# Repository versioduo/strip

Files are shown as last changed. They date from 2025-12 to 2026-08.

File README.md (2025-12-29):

# V2 strip
🚦 MIDI LED Strip

Drives a WS2812 LED strip. LEDs are controlled by incoming MIDI notes, the
brightness is controlled by the note velocity. Different MIDI channels use
different colors.

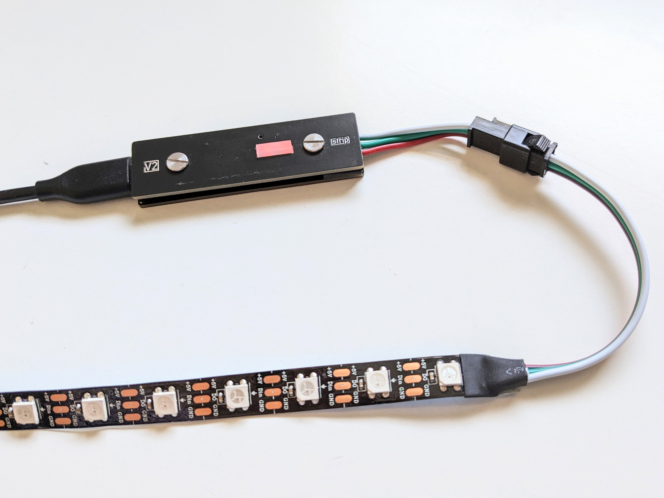
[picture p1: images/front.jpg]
strip hardware


## Screenshot
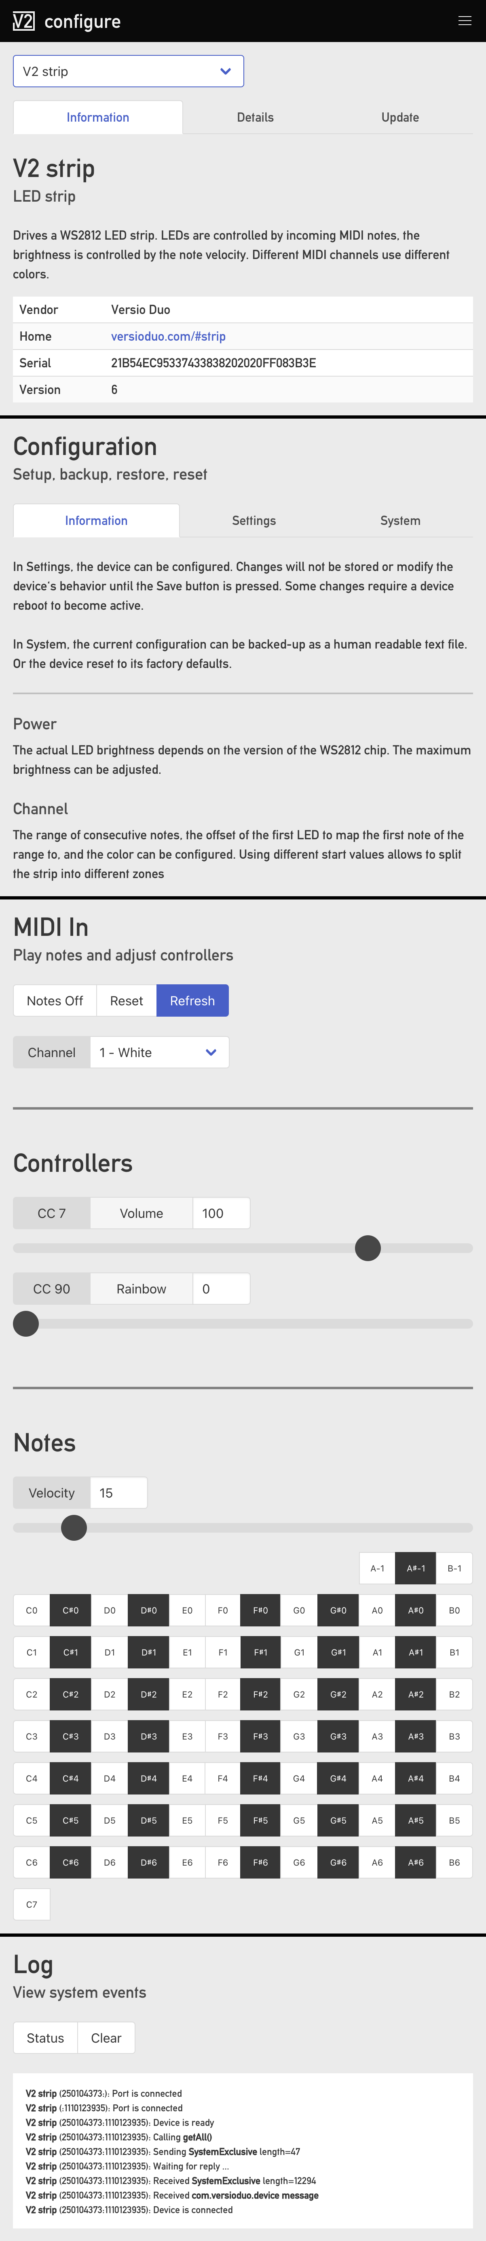
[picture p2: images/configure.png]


# Copying
Anyone can use this public domain work without having to seek authorisation, no one can ever own it.

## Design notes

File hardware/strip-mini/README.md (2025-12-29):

# V2 strip
🚦 MIDI LED Strip

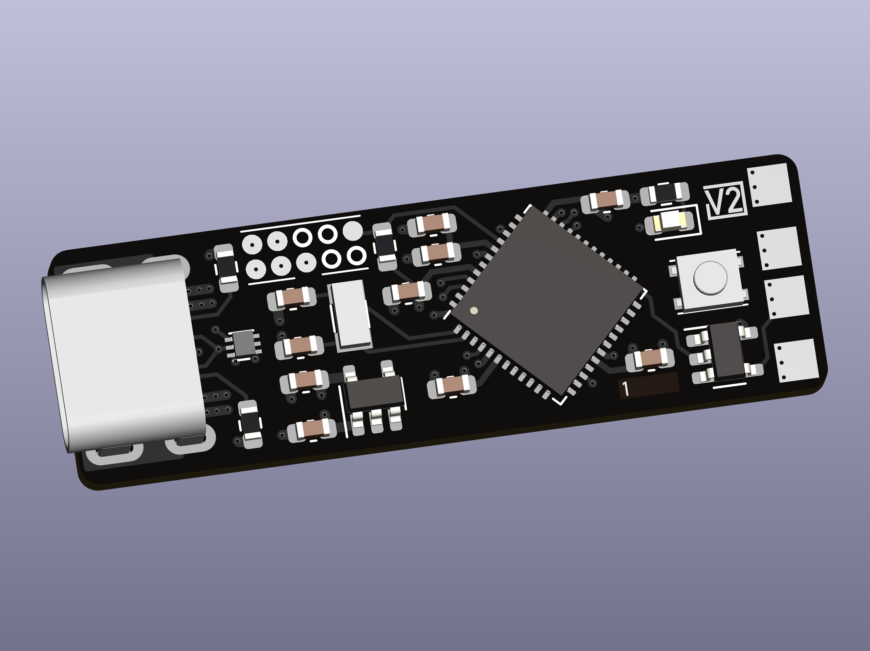
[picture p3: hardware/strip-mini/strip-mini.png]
board


## Video
[YouTube](https://www.youtube.com/watch?v=P1gKQrn-1O4)

## Schematic
[PDF](strip-mini.pdf)

## Bill Of Materials
[Interactive BOM](https://html-preview.github.io/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)

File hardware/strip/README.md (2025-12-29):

# V2 strip
🚦 MIDI LED Strip

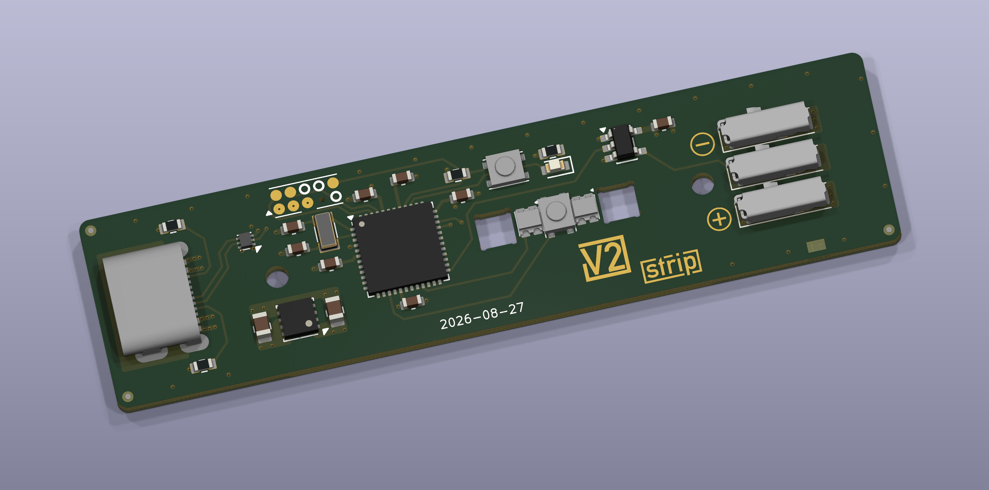
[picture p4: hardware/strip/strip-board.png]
board


## Video
[YouTube](https://www.youtube.com/watch?v=P1gKQrn-1O4)

## Schematic
[PDF](strip.pdf)

## Bill Of Materials
[Interactive BOM](https://html-preview.github.io/?url=https://github.com/versioduo/strip/blob/main/hardware/strip/strip-bom.html)

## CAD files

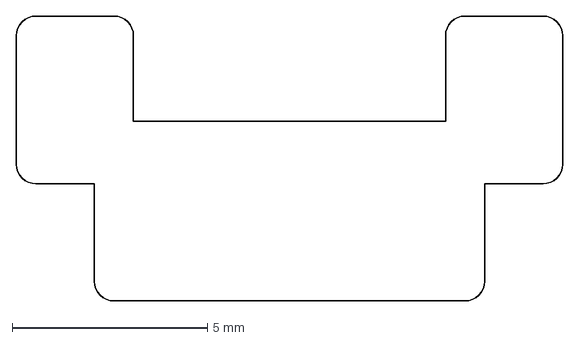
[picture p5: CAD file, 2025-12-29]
hardware/strip/button-laser.dxf
14.0 x 7.30 mm

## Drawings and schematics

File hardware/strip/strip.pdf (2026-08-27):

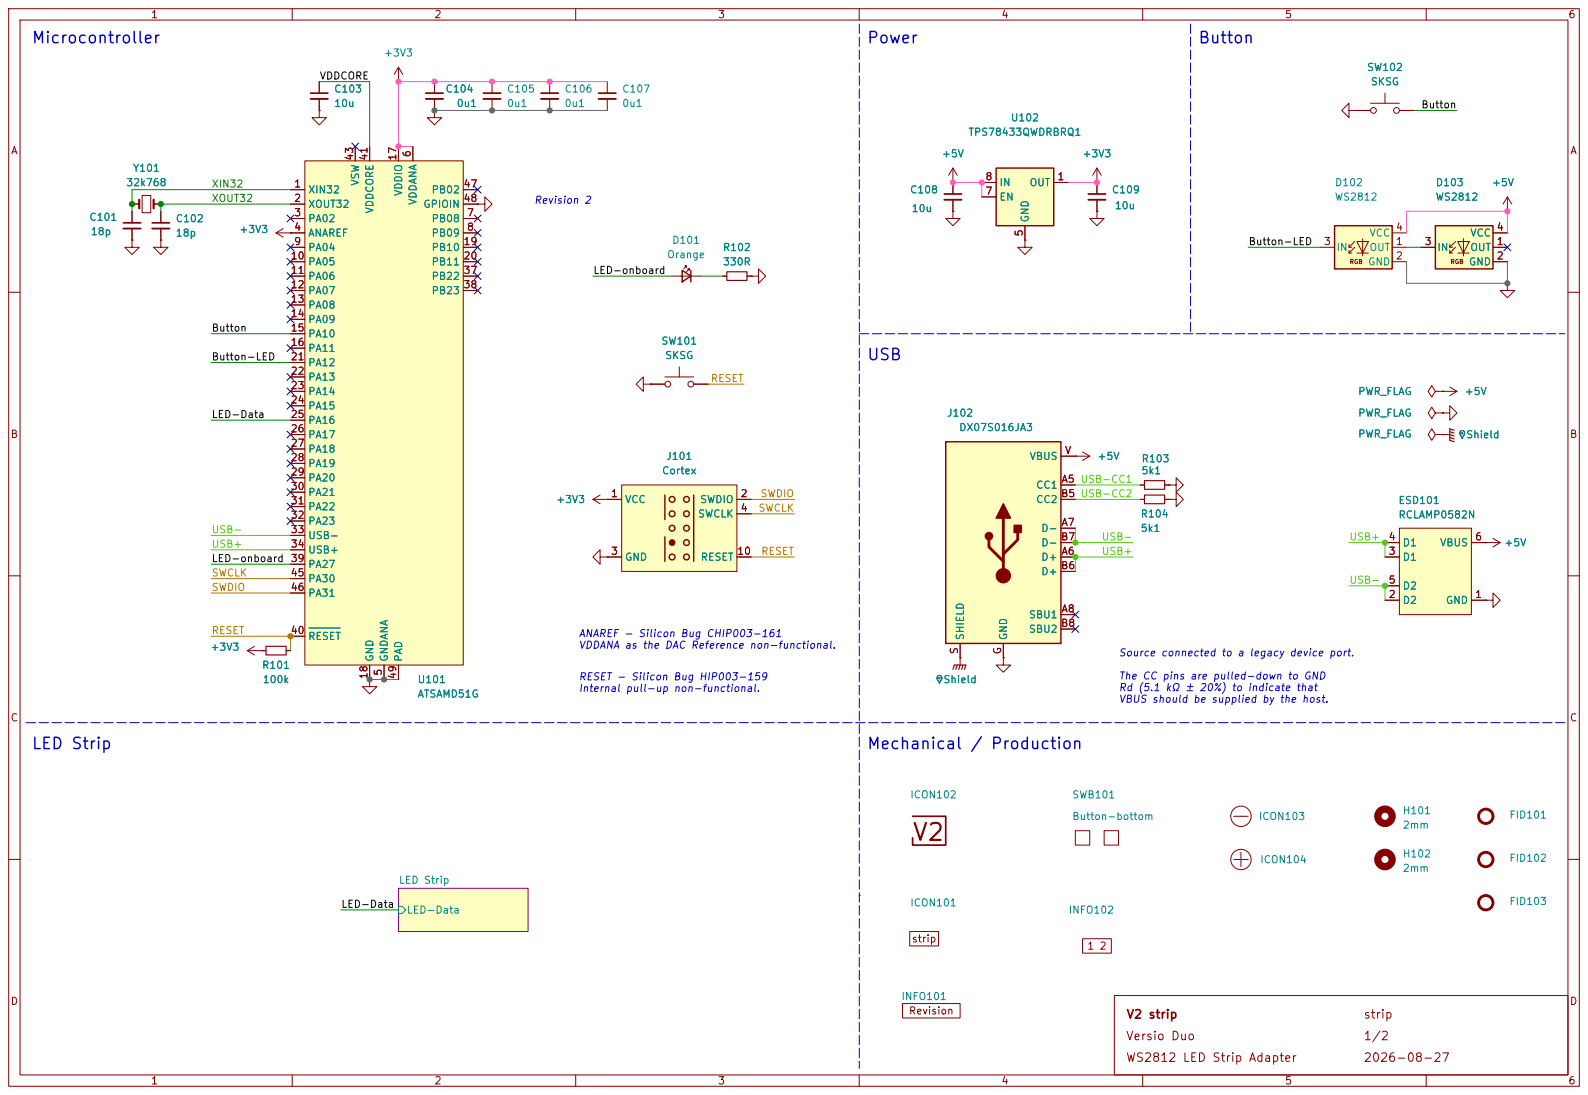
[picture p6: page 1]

Rd (5.1 kΩ ± 20%) to indicate that VBUS should be supplied by the host. Revision 2 RESET - Silicon Bug HIP003-159

LED-Data Button-LED

Source connected to a legacy device port. The CC pins are pulled-down to GND

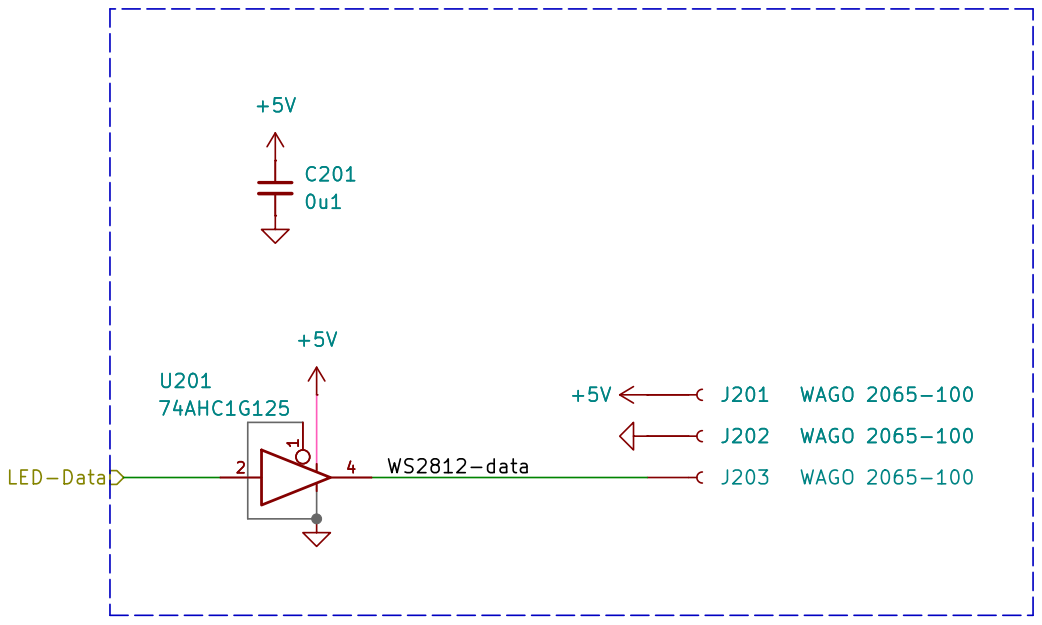
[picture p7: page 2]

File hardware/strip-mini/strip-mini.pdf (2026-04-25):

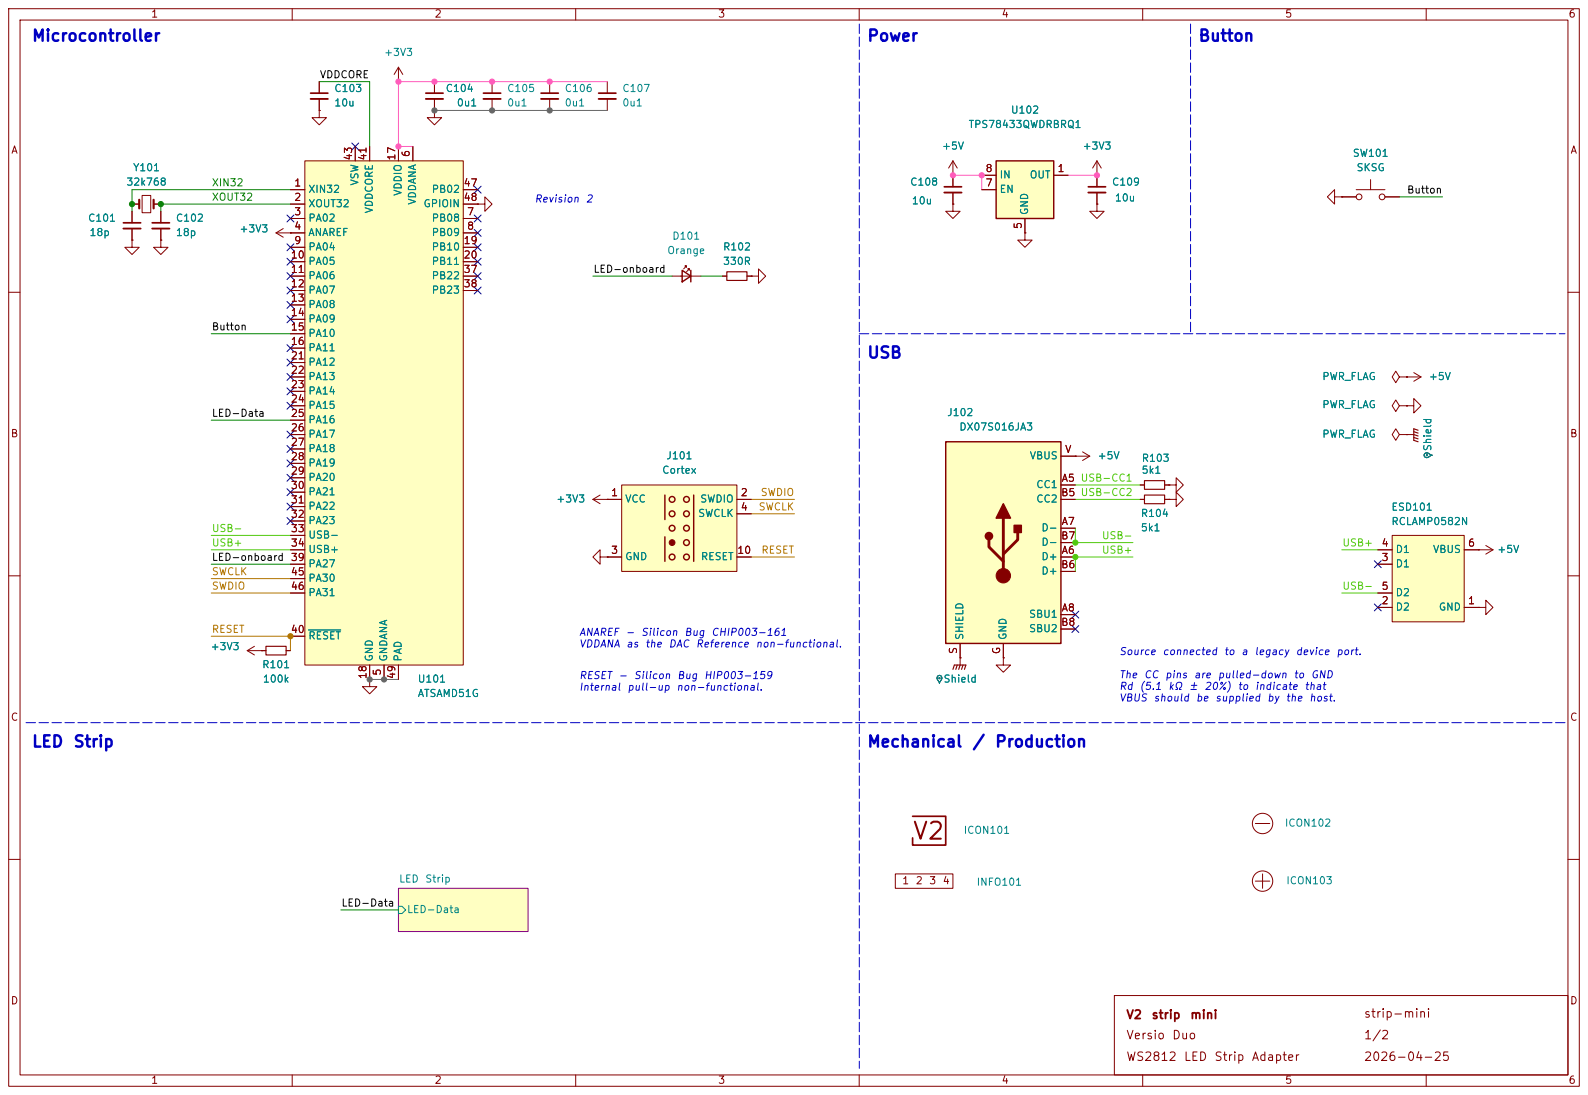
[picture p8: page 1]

Rd (5.1 kΩ ± 20%) to indicate that VBUS should be supplied by the host. Button

Internal pull-up non-functional. Revision 2 LED Strip

Source connected to a legacy device port. The CC pins are pulled-down to GND

strip-mini LED-Data

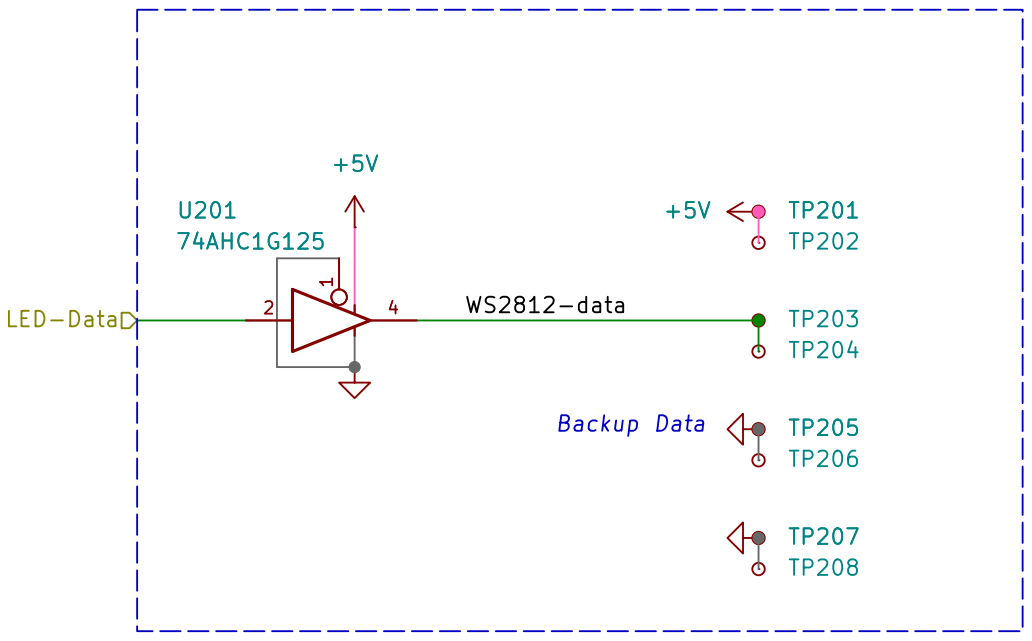
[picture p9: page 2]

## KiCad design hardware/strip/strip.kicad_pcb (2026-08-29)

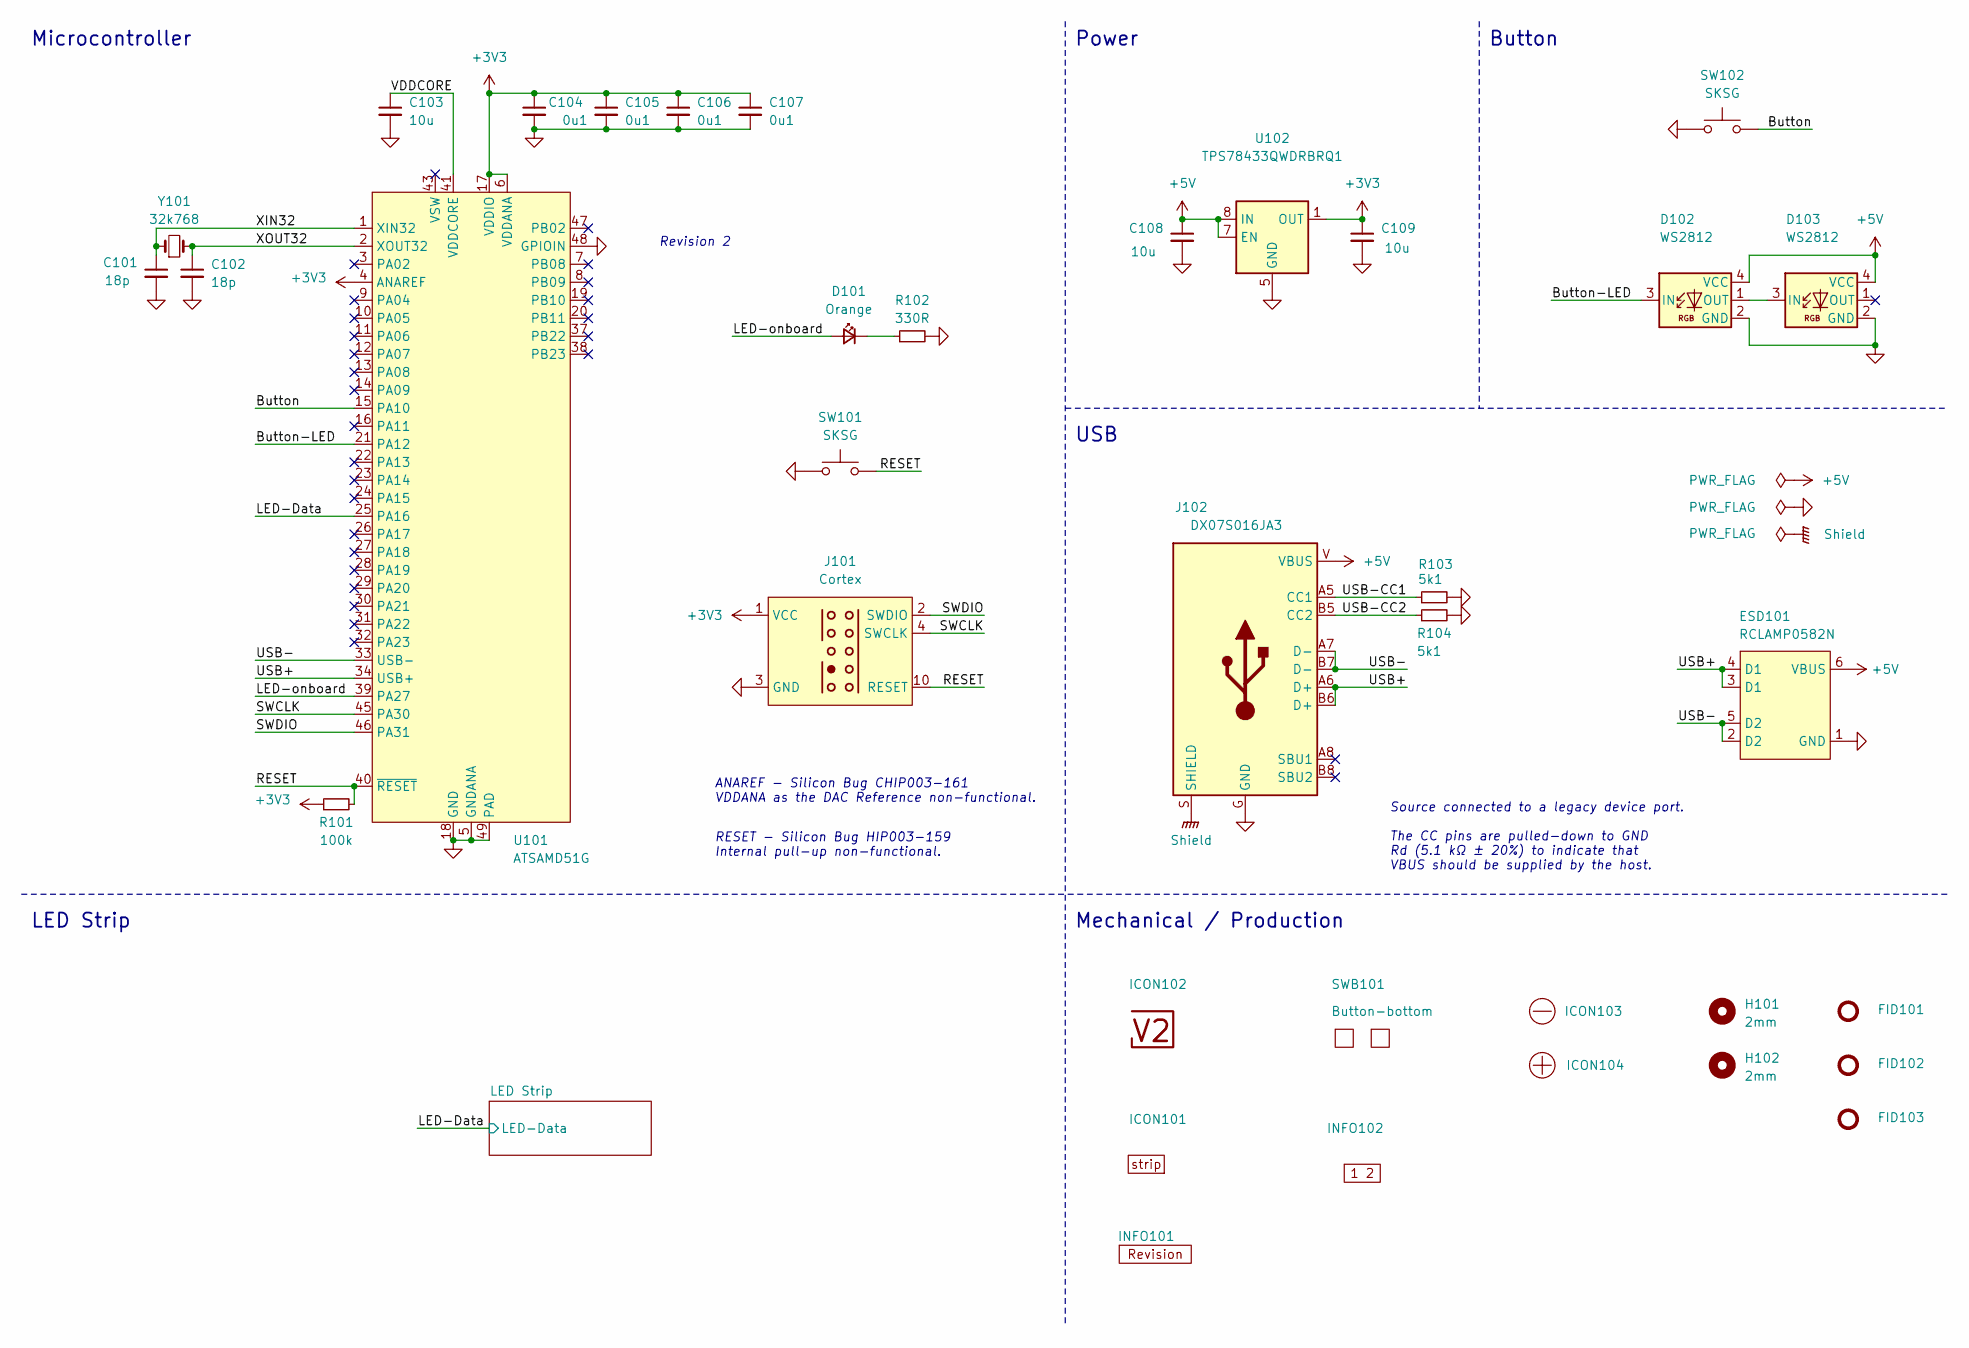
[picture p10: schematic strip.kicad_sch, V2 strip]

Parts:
C101, C102: 18p; C_1608; Rating 50V; Mouser 810-CGA3E2C0G1H180J
C103: 10u; C_1608; Rating 10V; Mouser 810-C1608X6S1A106M
C104, C105, C106, C107: 0u1; C_1608; Rating 50V; Mouser 810-CGA3E2X7R1H104MA
C108, C109: 10u; C_2012; Rating 25V; Mouser 810-C2012X5R1E106K
D101: Orange; LED_1608; Rating 605nm; Mouser 755-SML-D12D1WT86
D102, D103: WS2812; WS2812-2020; Rating 15mA; LCSC C965555
ESD101: RCLAMP0582N; SLP1210N6; Rating 20kV; Mouser 947-RCLAMP0582N.TCT
FID101, FID102, FID103: Fiducial_Paste; Fiducial_0.5mm_Mask1mm_Paste
H101, H102: 2mm; MountingHole_2mm
ICON101: Board_strip; Board_strip_Small
ICON102: V2-logo; Logo_Small
ICON103: Minus; Minus_Small
ICON104: Plus; Plus_Small
INFO101: Revision
INFO102: Layer_Numbers-4
J101: Cortex
J102: DX07S016JA3; JAE_DX07S016JA3; Rating USB2.0; Mouser 656-DX07S016JA3R1500
R101: 100k; R_1608; Rating 100mW; Mouser 71-CRCW0603100KFKEAC
R102: 330R; R_1608; Rating 100mW; Mouser 71-CRCW0603330RFKEAC
R103, R104: 5k1; R_1608; Rating 100mW; Mouser 71-CRCW06035K10FKEAC
SW101, SW102: SKSG; Rating 1.6N; Mouser 688-SKSGACE010
SWB101: Button-bottom; PCB_Button-bottom
U101: ATSAMD51G; QFN-48-1EP_7x7mm_P0.5mm_EP5.45x5.45mm_ThermalVias; Rating Cortex-M4F; Mouser 556-ATSAMD51G19AMU
U102: TPS78433QWDRBRQ1; VSON-8-1_3x3mm_P0.65_EP1.65x2.4mm; Rating 300mA; Mouser 595-TPS78433QWDRBRQ1
Y101: 32k768; Crystal_SMD_3215-2Pin_3.2x1.5mm; Rating 10ppm; Mouser 815-ABS0716632.768KT

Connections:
+3V3: C104.1, C105.1, C106.1, C107.1, C109.1, J101.1 (VCC), R101.1, U101.4 (ANAREF), U101.6 (VDDANA), U101.17 (VDDIO), U101.36 (VDDIO), U101.44 (VDDIO), U102.1 (OUT)
+5V: C108.1, D102.4 (VCC), D103.4 (VCC), ESD101.6 (VBUS), J102.V (VBUS), U102.6 (EN), U102.7 (EN), U102.8 (IN); also elsewhere on the board
/Button: SW102.2, U101.15 (PA10)
/Button-LED: D102.3 (IN), U101.21 (PA12)
/LED-Data: U101.25 (PA16); also elsewhere on the board
/LED-onboard: D101.2 (A), U101.39 (PA27)
/RESET: J101.10 (RESET), R101.2, SW101.2, U101.40 (~RESET)
/SWCLK: J101.4 (SWCLK), U101.45 (PA30)
/SWDIO: J101.2 (SWDIO), U101.46 (PA31)
/Shield: J102.S (SHIELD)
/USB+: ESD101.3 (D1), ESD101.4 (D1), J102.A6 (D+), J102.B6 (D+), U101.34 (USB+)
/USB-: ESD101.2 (D2), ESD101.5 (D2), J102.A7 (D-), J102.B7 (D-), U101.33 (USB-)
/USB-CC1: J102.A5 (CC1), R103.1
/USB-CC2: J102.B5 (CC2), R104.1
/VDDCORE: C103.1, U101.41 (VDDCORE)
/XIN32: C101.1, U101.1 (XIN32), Y101.1
/XOUT32: C102.1, U101.2 (XOUT32), Y101.2
GND: C101.2, C102.2, C103.2, C104.2, C105.2, C106.2, C107.2, C108.2, C109.2, D102.2 (GND), D103.2 (GND), ESD101.1 (GND), J101.3 (GND), J101.5 (GND), J102.G (GND), R102.2, R103.2, R104.2, SW101.1, SW102.1, U101.5 (GNDANA), U101.18 (GND), U101.35 (GND), U101.42 (GND), U101.48 (GPIOIN), U101.49 (PAD), U102.5 (GND), U102.9 (GND); also elsewhere on the board
unnamed: D101.1 (K), R102.1
unnamed: D102.1 (OUT), D103.3 (IN)

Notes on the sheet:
ANAREF -  Silicon Bug CHIP003-161 VDDANA as the DAC Reference non-functional.
RESET -  Silicon Bug HIP003-159 Internal pull-up non-functional.
 Source connected to a legacy device port. The CC pins are pulled-down to GND Rd (5.1 kΩ ± 20%) to indicate that VBUS should be supplied by the host.
Button
Revision 2
Power
Mechanical / Production
Microcontroller
USB
LED Strip

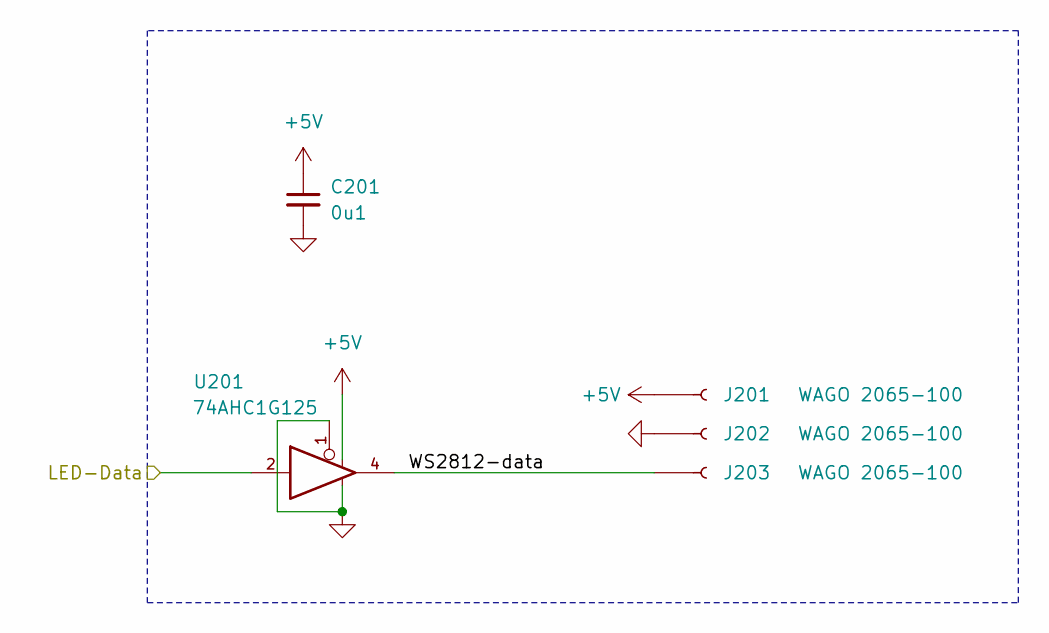
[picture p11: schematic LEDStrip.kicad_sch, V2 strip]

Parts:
C201: 0u1; C_1608; Rating 50V; Mouser 810-CGA3E2X7R1H104MA
J201, J202, J203: WAGO 2065-100; 2065-100; Rating 9A
U201: 74AHC1G125; SOT-23-5; Rating 8mA; Mouser 595-SN74AHC1G125DBVR

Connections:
+5V: C201.1, J201.1, U201.5; also elsewhere on the board
/LED Strip/WS2812-data: J203.1, U201.4
/LED-Data: U201.2; also elsewhere on the board
GND: C201.2, J202.1, U201.1, U201.3; also elsewhere on the board

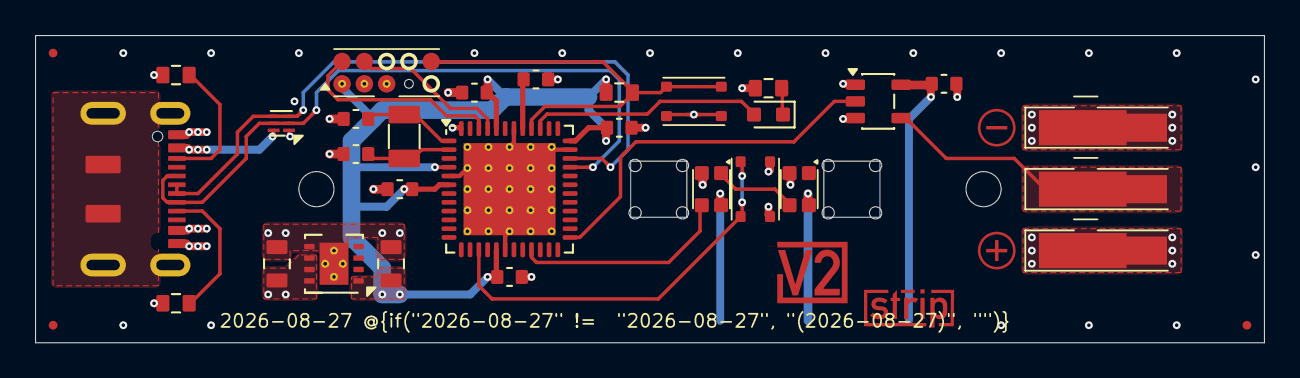
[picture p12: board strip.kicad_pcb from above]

Board: 4 copper layers, 70.0 x 17.5 mm, 41 parts (0 on the bottom side), 20 nets.

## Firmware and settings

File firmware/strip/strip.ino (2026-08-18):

#include <V2Base.h>
#include <V2Buttons.h>
#include <V2Device.h>
#include <V2LED.h>
#include <V2MIDI.h>
#include <V2Music.h>

namespace {
  V2Device::Info     Info{V2DeviceInfo("com.versioduo.strip", 19, "versioduo:samd:strip")};
  V2LED::WS2812<2>   LED(PIN_LED_WS2812, sercom2, SPI_PAD_0_SCK_1, PIO_SERCOM);
  V2LED::WS2812<128> LEDExt(PIN_LED_WS2812_EXT, sercom1, SPI_PAD_0_SCK_1, PIO_SERCOM);

  // Config, written to EEPROM.
  constexpr struct Configuration {
    enum class Program : uint8_t { Notes, Bar, _count };
    struct {
      uint8_t count{88};
      bool    reverse{};
      float   power{0.5};
    } leds;

    struct {
      char    name[32];
      uint8_t note{V2MIDI::A(-1)};
      uint8_t count{88};
      uint8_t start{};
      Program program{};
      struct {
        uint8_t h{0};
        uint8_t s{0};
        uint8_t v{127};
      } colour;
    } channels[16];

    float cNotes{};
  } ConfigurationDefault{.channels{
    {.name{"White"}},
    {.name{"Red"}, .colour{.h{0}, .s{127}}},
    {.name{"Green"}, .colour{.h{42}, .s{127}}},
    {.name{"Blue"}, .colour{.h{85}, .s{127}}},
    {.name{"Cyan"}, .colour{.h{63}, .s{127}}},
    {.name{"Magenta"}, .colour{.h{106}, .s{127}}},
    {.name{"Yellow"}, .colour{.h{21}, .s{127}}},
    {.name{"Orange"}, .colour{.h{11}, .s{127}}},
    {.name{"Amber"}, .colour{.h{8}, .s{127}}},
    {.name{"Pink"}, .colour{.h{116}, .s{100}}},
    {.name{"Lavender"}, .colour{.h{95}, .s{70}}},
    {.name{"Champagne"}, .colour{.h{12}, .s{100}}},
    {.name{"Desert"}, .colour{.h{10}, .s{40}}},
    {.name{"Aquamarine"}, .colour{.h{56}, .s{127}}},
    {.name{"Cornflower"}, .colour{.h{78}, .s{100}}},
    {.name{"Aqua"}, .colour{.h{77}, .s{50}}},
  }};

  class Device : public V2Device {
  public:
    Device() : V2Device() {
      metadata.vendor      = "Versio Duo";
      metadata.product     = "V2 strip";
      metadata.description = "LED strip";
      metadata.home        = "https://versioduo.com/#strip";
      help.device          = "Drives a WS2812 LED strip. LEDs are controlled by incoming MIDI notes, the "
                             "brightness is controlled by the note velocity. Different MIDI channels use "
                             "different colours.";
      help.configuration   = "# Power\n"
                             "The actual LED brightness depends on the version of the WS2812 "
                             "chip. The maximum brightness can be adjusted.\n"
                             "# Channel\n"
                             "The range of consecutive notes, the offset of the first LED to map the "
                             "first note of the range to, and the colour can be configured. Using "
                             "different start values allows to split the strip into different zones";
      system.download      = "https://versioduo.com/download";
      system.configure     = "https://versioduo.com/configure";
      usb.ports.standard   = 0;
      configuration        = {.version{2}, .size{sizeof(config)}, .data{&config}};
    }

    enum class CC {
      Volume  = V2MIDI::CC::ChannelVolume,
      CNotes  = V2MIDI::CC::Controller85,
      Rainbow = V2MIDI::CC::Controller90,
    };

    Configuration config{ConfigurationDefault};

    void updateRainbow(float brightness) {
      LEDExt.rainbow(1, 4.5f - (_rainbow * 4.f), brightness);
    }

  private:
    const char* _programNames[(uint8_t)Configuration::Program::_count]{"Notes", "Bar"};

    struct {
      uint8_t aftertouch;

      struct {
        bool                  active;
        V2Music::Playing<128> playing;
      } bar;

      struct {
        uint8_t velocity;
        uint8_t aftertouch;
      } notes[128];
    } _channels[16]{};

    struct {
      uint8_t channel;
      uint8_t brightness;
    } _leds[128]{};

    float               _volume{100.f / 127.f};
    float               _cNotes{};
    float               _rainbow{};
    uint32_t            _timeoutUsec{};
    V2Music::ForcedStop _force;

    void handleReset() override {
      _timeoutUsec = 0;
      _force.reset();

      allNotesOff();
    }

    void handleLoop() override {
      if (_timeoutUsec > 0 && V2Base::getUsecSince(_timeoutUsec) > 900 * 1000 * 1000)
        reset();
    }

    void allNotesOff() {
      if (_force.trigger()) {
        reset();
        return;
      }

      for (uint8_t ch = 0; ch < 16; ch++) {
        _channels[ch].aftertouch = 0;
        _channels[ch].bar.playing.reset();

        for (uint8_t i = 0; i < V2Base::countof(_channels[0].notes); i++) {
          _channels[ch].notes[i].aftertouch = 0;
          _channels[ch].notes[i].velocity   = 0;
        }
      }

      for (uint8_t i = 0; i < V2Base::countof(_leds); i++)
        _leds[i] = {};

      _volume  = 100.f / 127.f;
      _cNotes  = config.cNotes;
      _rainbow = 0;
      LED.reset();
      LED.hsv({V2Colour::Orange, 0.95, 0.25});

      LEDExt.reset();
      updateLEDs(true);
    }

    // Show individual notes.
    void updateLEDsNotes(bool force = false) {
      for (uint8_t i = 0; i < config.leds.count; i++) {
        uint8_t channel    = 0;
        uint8_t brightness = 0;

        // Find an active note in one of the 16 channels. The note in the
        // highest channel number wins.
        for (int8_t ch = 15; ch >= 0; ch--) {
          if (config.channels[ch].program != Configuration::Program::Notes)
            continue;

          if (i < config.channels[ch].start)
            continue;

          if (i >= config.channels[ch].start + config.channels[ch].count)
            continue;

          const uint8_t note = config.channels[ch].note + i - config.channels[ch].start;
          if (note > 127)
            continue;

          if (_channels[ch].notes[note].velocity == 0)
            continue;

          channel = ch;
          if (_channels[ch].notes[note].aftertouch > 0) {
            brightness = _channels[ch].notes[note].aftertouch;
          }

          else if (_channels[channel].aftertouch > 0) {
            brightness = _channels[channel].aftertouch;
          }

          else {
            brightness = _channels[ch].notes[note].velocity;
          }

          break;
        }

        if (brightness == 0 && _cNotes > 0.f) {
          uint8_t note = V2MIDI::A(-1) + i;
          uint8_t key  = note % 12;
          if (key == 0)
            brightness = _cNotes * 127.f;
        }

        if (!force && _leds[i].channel == channel && _leds[i].brightness == brightness)
          continue;

        _leds[i].channel    = channel;
        _leds[i].brightness = brightness;

        if (brightness == 0) {
          LEDExt.brightness(0, i);
          continue;
        }

        auto h{(float)config.channels[channel].colour.h / 127.f * 360.f};
        auto s{(float)config.channels[channel].colour.s / 127.f};
        auto v{(float)config.channels[channel].colour.v / 127.f};
        auto fraction{(float)brightness / 127.f};
        auto adjusted{0.1f + (0.9f * fraction)};
        LEDExt.hsv({h, s, _volume * adjusted * v}, i);
      }
    }

    // Flash an LED bar, the length depending on the note velocity.
    void updateLEDsBar() {
      for (int8_t ch = 15; ch >= 0; ch--) {
        if (config.channels[ch].program != Configuration::Program::Bar)
          continue;

        uint8_t note;
        uint8_t velocity;
        if (!_channels[ch].bar.playing.getLast(note, velocity)) {
          if (!_channels[ch].bar.active)
            continue;

          for (uint8_t i = 0; i < config.channels[ch].count; i++)
            LEDExt.brightness(0, config.channels[ch].start + i);

          _channels[ch].bar.active = false;
          continue;
        }

        auto h{float{config.channels[ch].colour.h / 127.f * 360.f}};
        auto s{float{config.channels[ch].colour.s / 127.f}};
        auto v{float{config.channels[ch].colour.v / 127.f}};
        auto fractionBrightness{float(_channels[ch].aftertouch > 0 ? _channels[ch].aftertouch : 127.f) / 127.f};
        auto brightness{_volume * fractionBrightness * v};
        auto count{ceilf((float)config.channels[ch].count * ((float)velocity / 127.f))};
        for (uint8_t i = 0; i < count; i++)
          LEDExt.hsv({h, s, brightness}, config.channels[ch].start + i);

        for (uint8_t i = count; i < config.channels[ch].count; i++)
          LEDExt.brightness(0, config.channels[ch].start + i);

        _channels[ch].bar.active = true;
      }
    }

    void updateLEDs(bool force = false) {
      updateLEDsNotes(force);
      updateLEDsBar();
    }

    void handleNote(uint8_t channel, uint8_t note, uint8_t velocity) override {
      switch (config.channels[channel].program) {
        case Configuration::Program::Notes:
          _channels[channel].notes[note].velocity = velocity;
          if (velocity == 0) {
            _channels[channel].aftertouch             = 0;
            _channels[channel].notes[note].aftertouch = 0;
          }
          break;

        case Configuration::Program::Bar:
          _channels[channel].bar.playing.update(note, velocity);
          break;
      }

      updateLEDs();
      _timeoutUsec = V2Base::getUsec();
    }

    void handleNoteOff(uint8_t channel, uint8_t note, uint8_t velocity) override {
      handleNote(channel, note, 0);
      _timeoutUsec = V2Base::getUsec();
    }

    void handleAftertouch(uint8_t channel, uint8_t note, uint8_t pressure) override {
      _channels[channel].notes[note].aftertouch = pressure;

      updateLEDs();
      _timeoutUsec = V2Base::getUsec();
    }

    void handleAftertouchChannel(uint8_t channel, uint8_t pressure) override {
      _channels[channel].aftertouch = pressure;

      updateLEDs();
      _timeoutUsec = V2Base::getUsec();
    }

    void handleControlChange(uint8_t channel, uint8_t controller, uint8_t value) override {
      switch (controller) {
        case (uint8_t)CC::Volume:
          _volume = (float)value / 127.f;
          if (_rainbow > 0.f)
            updateRainbow(_volume);

          else
            updateLEDs(true);
          break;

        case (uint8_t)CC::CNotes:
          _cNotes = (float)value / 127.f;
          updateLEDs(true);
          break;

        case (uint8_t)CC::Rainbow:
          _rainbow = (float)value / 127.f;
          if (_rainbow <= 0.f) {
            LEDExt.reset();
            updateLEDs(true);

          } else {
            updateRainbow(_volume);
          }
          break;

        case V2MIDI::CC::AllSoundOff:
        case V2MIDI::CC::AllNotesOff:
          allNotesOff();
          break;
      }

      _timeoutUsec = V2Base::getUsec();
    }

    void handleSystemExclusive(const uint8_t* buffer, uint32_t len) override {
      if (len < 10)
        return;

      // 0x7d == SysEx prototype/research/private ID
      if (buffer[1] != 0x7d)
        return;

      // Handle only JSON messages.
      if (buffer[2] != '{' || buffer[len - 2] != '}')
        return;

      // Read incoming message.
      JsonDocument json;
      if (deserializeJson(json, buffer + 2, len - 1))
        return;

      JsonObject jsonLed = json["led"];
      if (!jsonLed)
        return;

      JsonArray jsonColours = jsonLed["colours"];
      if (!jsonColours)
        return;

      const uint8_t start = jsonLed["start"];
      for (uint8_t i = 0; i + start < 128; i++) {
        JsonArray jsonColour = jsonColours[i];
        if (!jsonColour)
          break;

        // Empty array, skip LED.
        if (jsonColour[2].isNull())
          continue;

        uint8_t hue = jsonColour[0];
        if (hue > 127)
          hue = 127;

        uint8_t saturation = jsonColour[1];
        if (saturation > 127)
          saturation = 127;

        uint8_t brightness = jsonColour[2];
        if (brightness > 127)
          brightness = 127;

        LEDExt.hsv({float(hue) / 127.f * 360.f, float(saturation) / 127.f, float(brightness) / 127.f}, i + start);
      }

      _timeoutUsec = V2Base::getUsec();
    }

    void handleSystemReset() override {
      reset();
    }

    void exportInput(JsonObject json) override {
      JsonArray jsonChannels = json["channels"].to<JsonArray>();
      for (uint8_t ch = 0; ch < 16; ch++) {
        JsonObject jsonChannel = jsonChannels.add<JsonObject>();
        jsonChannel["number"]  = ch;
        jsonChannel["name"]    = config.channels[ch].name;

        JsonArray jsonControllers = jsonChannel["controllers"].to<JsonArray>();
        {
          JsonObject jsonController = jsonControllers.add<JsonObject>();
          jsonController["name"]    = "Volume";
          jsonController["number"]  = (uint8_t)CC::Volume;
          jsonController["value"]   = (uint8_t)(_volume * 127.f);
        }
        {
          JsonObject jsonController = jsonControllers.add<JsonObject>();
          jsonController["name"]    = "C Notes";
          jsonController["number"]  = (uint8_t)CC::CNotes;
          jsonController["value"]   = (uint8_t)(_cNotes * 127.f);
        }
        {
          JsonObject jsonController = jsonControllers.add<JsonObject>();
          jsonController["name"]    = "Rainbow";
          jsonController["number"]  = (uint8_t)CC::Rainbow;
          jsonController["value"]   = (uint8_t)(_rainbow * 127.f);
        }
        {
          JsonObject jsonAftertouch = jsonChannel["aftertouch"].to<JsonObject>();
          jsonAftertouch["value"]   = _channels[ch].aftertouch;
        }
        {
          JsonObject jsonChromatic = jsonChannel["chromatic"].to<JsonObject>();
          switch (config.channels[ch].program) {
            case Configuration::Program::Notes:
              jsonChromatic["start"] = config.channels[ch].note;
              jsonChromatic["count"] = config.channels[ch].count;
              break;

            case Configuration::Program::Bar:
              jsonChromatic["start"] = 0;
              jsonChromatic["count"] = 127;
              break;
          }
        }
      }
    }

    void exportSettings(JsonArray json) override {
      {
        JsonObject setting = json.add<JsonObject>();
        setting["type"]    = "number";
        setting["title"]   = "LED";
        setting["label"]   = "Count";
        setting["min"]     = 1;
        setting["max"]     = 128;
        setting["default"] = ConfigurationDefault.leds.count;
        setting["path"]    = "leds/count";
      }
      {
        JsonObject setting = json.add<JsonObject>();
        setting["type"]    = "toggle";
        setting["label"]   = "Reverse";
        setting["default"] = ConfigurationDefault.leds.reverse;
        setting["path"]    = "leds/reverse";
      }
      {
        JsonObject setting = json.add<JsonObject>();
        setting["type"]    = "number";
        setting["label"]   = "Power";
        setting["min"]     = 0;
        setting["max"]     = 1;
        setting["step"]    = 0.01;
        setting["default"] = ConfigurationDefault.leds.power;
        setting["path"]    = "leds/power";
      }
      {
        JsonObject setting = json.add<JsonObject>();
        setting["type"]    = "number";
        setting["title"]   = "Guide";
        setting["label"]   = "C Notes";
        setting["min"]     = 0;
        setting["max"]     = 1;
        setting["step"]    = 0.01;
        setting["default"] = ConfigurationDefault.cNotes;
        setting["path"]    = "cNotes";
      }

      for (uint8_t ch = 0; ch < 16; ch++) {
        {
          JsonObject setting = json.add<JsonObject>();
          setting["type"]    = "title";

          char name[64];
          sprintf(name, "Channel %d", ch + 1);
          setting["title"] = name;
        }
        {
          JsonObject setting = json.add<JsonObject>();
          setting["type"]    = "text";
          setting["label"]   = "Name";

          char path[64];
          sprintf(path, "channels[%d]/name", ch);
          setting["path"] = path;
        }
        {
          JsonObject setting = json.add<JsonObject>();
          setting["type"]    = "number";
          setting["label"]   = "Program";
          setting["max"]     = (uint8_t)Configuration::Program::_count - 1;
          setting["input"]   = "select";
          JsonArray names    = setting["names"].to<JsonArray>();
          for (uint8_t i = 0; i < (uint8_t)Configuration::Program::_count; i++)
            names.add(_programNames[i]);

          char path[64];
          sprintf(path, "channels[%d]/program", ch);
          setting["path"] = path;
        }
        {
          JsonObject setting = json.add<JsonObject>();
          setting["type"]    = "number";
          setting["label"]   = "LED";
          setting["text"]    = "Start";
          setting["min"]     = 1;
          setting["max"]     = 128;

          char path[64];
          sprintf(path, "channels[%d]/start", ch);
          setting["path"] = path;
        }
        {
          JsonObject setting = json.add<JsonObject>();
          setting["type"]    = "number";
          setting["label"]   = "LED";
          setting["text"]    = "Count";
          setting["max"]     = 128;

          char path[64];
          sprintf(path, "channels[%d]/count", ch);
          setting["path"] = path;
        }
        {
          JsonObject setting = json.add<JsonObject>();
          setting["type"]    = "note";
          setting["label"]   = "Note";

          setting["default"] = ConfigurationDefault.channels[ch].note;

          char path[64];
          sprintf(path, "channels[%d]/note", ch);
          setting["path"] = path;
        }
        {
          JsonObject setting = json.add<JsonObject>();
          setting["type"]    = "colour";
          setting["ruler"]   = true;

          char path[64];
          sprintf(path, "channels[%d]/colour", ch);
          setting["path"] = path;
        }
      }
    }

    void importConfiguration(JsonObject json) override {
      JsonObject jsonLeds = json["leds"];
      if (jsonLeds) {
        if (!jsonLeds["count"].isNull()) {
          uint8_t count = jsonLeds["count"];
          if (count > 128)
            count = 128;
          config.leds.count = count;
        }

        if (!jsonLeds["reverse"].isNull())
          config.leds.reverse = jsonLeds["reverse"];

        if (!jsonLeds["power"].isNull())
          config.leds.power = jsonLeds["power"];
      }

      if (!json["cNotes"].isNull()) {
        float cNotes = json["cNotes"];
        if (cNotes > 1.f) {
          cNotes = 1;
        }

        else if (cNotes < 0.f) {
          cNotes = 0;
        }

        config.cNotes = cNotes;
      }

      JsonArray jsonChannels = json["channels"];
      if (jsonChannels) {
        for (uint8_t ch = 0; ch < 16; ch++) {
          if (jsonChannels[ch].isNull())
            break;

          const char* name = jsonChannels[ch]["name"];
          if (name)
            strlcpy(config.channels[ch].name, name, sizeof(config.channels[ch].name));

          if (!jsonChannels[ch]["program"].isNull()) {
            uint16_t program = jsonChannels[ch]["program"];
            if (program > (uint8_t)Configuration::Program::_count - 1)
              program = (uint8_t)Configuration::Program::_count - 1;

            config.channels[ch].program = (Configuration::Program)program;
          }

          if (!jsonChannels[ch]["start"].isNull()) {
            uint16_t led = jsonChannels[ch]["start"];
            if (led < 1)
              led = 1;
            if (led > 128)
              led = 128;

            config.channels[ch].start = led - 1;
          }

          if (!jsonChannels[ch]["count"].isNull()) {
            uint16_t count = jsonChannels[ch]["count"];
            if (count > 128)
              count = 128;

            config.channels[ch].count = count;
          }

          if (!jsonChannels[ch]["note"].isNull()) {
            uint16_t note = jsonChannels[ch]["note"];
            if (note > 127)
              note = 127;

            config.channels[ch].note = note;
          }

          JsonArray jsonColour = jsonChannels[ch]["colour"];
          if (!jsonColour)
            jsonColour = jsonChannels[ch]["color"];
          if (jsonColour) {
            uint8_t colour = jsonColour[0];
            if (colour > 127)
              colour = 127;
            config.channels[ch].colour.h = colour;

            uint8_t saturation = jsonColour[1];
            if (saturation > 127)
              saturation = 127;
            config.channels[ch].colour.s = saturation;

            uint8_t brightness = jsonColour[2];
            if (brightness > 127)
              brightness = 127;
            config.channels[ch].colour.v = brightness;
          }
        }
      }

      _cNotes = config.cNotes;
      LEDExt.resize(config.leds.count);
      LEDExt.reverse(config.leds.reverse);
      LEDExt.brightnessMax(config.leds.power);
      updateLEDs(true);
    }

    void exportConfiguration(JsonObject json) override {
      {
        json["#leds"]       = "The properties of the connected LEDs";
        JsonObject jsonLeds = json["leds"].to<JsonObject>();
        jsonLeds["#count"]  = "The number of LEDs to drive";
        jsonLeds["count"]   = config.leds.count;

        jsonLeds["#reverse"] = "The direction of the strip";
        jsonLeds["reverse"]  = config.leds.reverse;

        jsonLeds["#power"] = "The maximum brightness of the LEDs (0..1)";
        jsonLeds["power"]  = serialized(String(config.leds.power, 2));
      }

      json["#cNotes"] = "Mark the C notes with a blue dot (0..1)";
      json["cNotes"]  = serialized(String(config.cNotes, 2));

      json["#channels"]      = "The MIDI channels with different colours and zones";
      JsonArray jsonChannels = json["channels"].to<JsonArray>();
      for (uint8_t i = 0; i < 16; i++) {
        JsonObject jsonChannel = jsonChannels.add<JsonObject>();
        jsonChannel["name"]    = config.channels[i].name;
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
void loop() {
  LED.loop();
  LEDExt.loop();
  MIDI.loop();
  V2Buttons::loop();
  Device.loop();

  if (Device.idle())
    Device.sleep();
}

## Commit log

2026-02-13 Replace Order_Number
    [LEDStrip.kicad_sch, strip-cover.kicad_pcb, strip-cover.kicad_sch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]
2026-02-15 Update Library
    [LEDStrip.kicad_sch, strip-cover.kicad_pcb, strip-cover.kicad_sch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]
2026-03-14 Update ESD suppressor
    [LEDStrip.kicad_sch, strip-mini.kicad_pcb, strip-mini.kicad_sch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]
2026-05-11 Good Bye Imperial
    [strip-mini.kicad_sch, strip.kicad_sch]
